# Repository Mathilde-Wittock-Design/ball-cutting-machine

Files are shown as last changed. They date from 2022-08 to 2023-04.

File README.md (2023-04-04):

# Ball Cutting Machine
This project is part of the [Soundbounce Design Project](<https://graduateshowcase.arts.ac.uk/projects/247648/cover>).  
Soundbounce is a product made from reclaimed tennis balls.



## Objectives
The machine should be an assembly of standard tools and accessible to Opendesk manufacturers.  
Opendesk manufacturers are mainly located in North America and Western Europe.  
The machine should be assembled from a downloadable file/template.  

Main objectives:
- [ ] Reduce cutting time.
- [ ] Require minimum effort.
- [ ] Be affordable and accessible.
- [ ] Be safe.

## Propositions
At the moment, the machine can be an adapter that can be attached to a drill press.  
In the future, this machine could probably become an adapter that can be attached to a CNC machine.  
The drill press for cutting tennis balls seems to need an adapter to hold the appropriate cutting tool and a tray to hold the tennis balls in place during cutting.

### Constraints? Guidelines?
Since this is to be shared and intended for makers, it is important to base our choices on repeatability and accessibility.  
Therefore, we need to take into account:  
- Quality brands that are likely to already be in the range of professional makers, such as Fein, Bosch, Makita, and Ryobi.
- Open-source software and easy-to-access documentation that is not paid.
- 3D printing FDM, PLA filament, PETG, and nothing too specific.

### Conceptual Sketches
#### - The Sawing Stand:
sketch1

#### - The Clamping Base for 3 Balls:
sketch2

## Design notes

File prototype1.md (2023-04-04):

# Prototype No. 1

The first version of the "clamping base" is designed to hold a tennis ball while undergoing a vertical cut with a vibrating saw mounted on a drilling stand. The constraints were as follows:  
1. Keeping the ball properly secured despite its loss of volume and density as successive cuts were made.
2. Properly securing the ball against pressure and vibration.
3. Making a straight cut up to the middle of the ball.

Following the guidelines, our solutions to these different problems were as follows:
1. We opted to hold the ball with a spring-loaded clamp that adapts to the different sizes and density changes of the ball during the operation.
2. We added heavy-duty grip tape to the inside of the clamps, as well as screws whose tips come out inside the clamp, in order to create even more resistance to vibration.
3. We made a right-angle table to install the clamps vertically so that we can cut up to half the ball with no obstruction from the clamp. We added tabs to locate every clamp and ease the alignment with the blade.

genPictV1

## Lists of Components
#### Stand

We opted for this sturdy, rigid, and adjustable drill stand, which allows us to adjust the cutting height and the exact positioning of the vibrating saw. And we chose this model of Bosch multitool for its rigid "starlock" clamping ring that allowed us to hold on to it. The use in a fixed station did not require the cordless version, which offers the advantage of being less expensive.



- ["Drilling milling stand BF1240"](<https://www.wabeco-remscheid.de/catalog/category/view/s/bf1240/id/352/>)
- Multi-cutter "Bosch professional GOP 30-28"
- Saw blade "E-Cut SLP Standard HCS 50x65"

#### Clamping base
- Spring clamp "FZ 60 - wolfcraft 3631000"
- Toggle Clamps "GH-201-B"
- Wood Multiplex 18mm
- 3D model to 3D print in [/Files/clamp](https://github.com/Mathilde-Wittock-Design/ball-cutting-machine/tree/main/Files)



#### Tool clamp
- 3D model to 3D print in [/Files/holder](https://github.com/Mathilde-Wittock-Design/ball-cutting-machine/tree/main/Files)



## Assembly

1. Attach the drilling stand to the workbench using at least two bolts.
2. Attach the adapter to the end of the horizontal hexagonal rod so that it is flush with the edge of the rod.
3. Position the vibrating saw in the adapter, tighten the clamping screw slightly, and insert the blade.
4. Bolt the fixed part of the board to the stand without tightening.
5. Place the movable part of the board against the fixed part in the first notch, place a ball in the first clamp, and adjust the fixed part of the board so that the center of the ball is aligned with the center of the blade.
6. Tighten the fixed part of the board.
7. Close the toggle clamps to lock the position of the movable part, then check the alignment of the blade with the board using a square.
8. Lock the square with a clamp and then firmly screw the saw's clamping screw onto the adapter.
9. Adjust the cutting height (Z-axis) and depth (Y-axis) manually (refer to the drilling stand manual).

## Tablet construction

sketch2

- Cut the three parts of the tablet to the dimensions indicated on the diagram.
- The two parts of the flat, horizontal face are cut at a 45° angle like a "French cleat" so that the mobile part slides under the fixed part.
- The third part is fixed at a right angle to the second, composing the mobile part of the tablet.
- In the fixed part, drill two holes so that it can be bolted to the base, then fix it.
- Trace the center of the blade on the fixed part, then make a "dovetail" notch centered on the blade.
- Cut out the negative of this notch and stick it inside to obtain a notch.

dimensions de la tablette

- Cut out a notch in the mobile part of the tablet corresponding to this notch, for each clamp you wish to put on this tablet, the recommended space between these notches is 12/16 cm to provide space for the clamps but also to place the hand outside the cut.
- Determine the location of the clamps centered opposite the notches of the mobile part, on the vertical part, by already positioning a ball in each, in order to center the ball and not the clamp.
Ensure that the ball protrudes sufficiently in height to pass over the horizontal tablet.
- Mark the location of the clamp and outline the spring housing.
- Remove the clamp and hollow out the spring housing location with a wood chisel in the tablet so that it can fit completely and no longer interfere with the stability of the clamp.
- Place the clamp again and fix it by drilling one of the two handles in three points, in order to keep its ability to open and close while fixing it securely.

alignement tablette

---

### Remarques et problèmes rencontrés. 
- le grip des balles
- la flexibilité de la lame
- la mise à l'équerre de la scie // à la tablette

### Recherche du rendement. 
- la pièce de callage de balle, pour faciliter l'alignement des balles. 
- production de plusieurs tablettes
- travail d'équipe
- confort, sécurité et endurance 

### upgrade futur et piste de développement
"Ultrasonic cutter" utilisé dans l'industrie alimentaire.

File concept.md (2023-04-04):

**This machine is designed to be replicated or improved to enable upcycling of tennis balls in a distributed manner. The plans will be published on GitHub under a free license, with attribution (CC BY 4.0).**

## Concept
_"This machine is designed to be reproduced or improved,"_  
meaning it is designed to be manufactured in other fablabs or makerspaces, or improved and adapted as needed.
The design must therefore exclude the use of non-standard components, or provide information on how to make them.
For example, the vibrating saw is not a Bosch but a Fein or a Makita, and the tool holding clamp does not match and must be adapted to the new shape. The editable 3D model is provided to make the update.  
We select tools like Bosch because the brand is reputable, professional, and readily available.

_"and enable upcycling of tennis balls in a distributed way."_  
Upcycling, as opposed to recycling, means transforming or reusing the ball for a new function than what it was originally intended for. Here, the ball is cut in half and finds a new life and function as sound absorption.


source: https://himalayan-made.fr/2020/01/07/upcycler-et-recycler-quelle-est-la-di%EF%AC%80erence/

_"Distributed production:"_  
This is the main proposal of Opendesk. Instead of having a centralized factory, they have a network of workshops for distributed production. This way, the production process is decentralized and potentially associated with local networks for decentralized pickup of the products.


source: https://blogs.aalto.fi/makerculture/2017/10/19/localizing-and-distributing-production/

## License
_"The plans will be published on GitHub under an open license with attribution (CC BY 4.0)."_  
As a consequence of these goals, the plans must be shared openly so that anyone who wants to participate in the ball cutting can do so.

We propose publishing the plans on GitHub, which is a platform that allows for protection, distribution, and collaboration on software, hardware, and other projects.

The suggested license is CC BY 4.0, which is the creative commons version 4.0 with attribution.  
https://creativecommons.org/2013/11/25/ccs-next-generation-licenses-welcome-version-4-0/  

which mean that 
### you are free to:
**Share** — copy and redistribute the material in any medium or format  
**Adapt** — remix, transform, and build upon the material for any purpose, even commercially.  
### Under the following terms:
**Attribution** — You must give appropriate credit, provide a link to the license, and indicate if changes were made. You may do so in any reasonable manner, but not in any way that suggests the licensor endorses you or your use.  
**ShareAlike** — If you remix, transform, or build upon the material, you must distribute your contributions under the same license as the original.

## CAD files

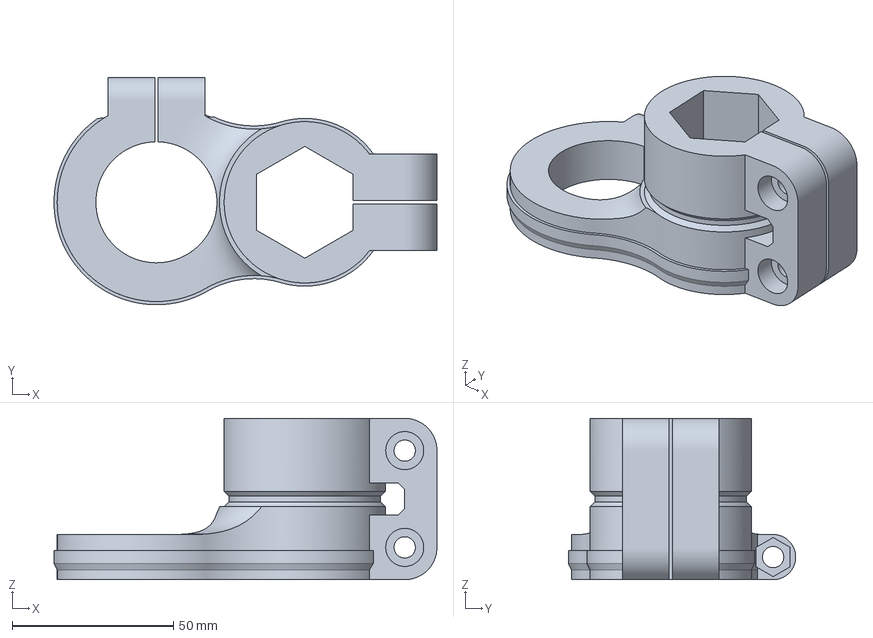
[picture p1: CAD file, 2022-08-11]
Files/SB_Clamp.3mf
118.7 x 70.5 x 50.0 mm

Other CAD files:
Files/SB_Clamp.f3d
Files/SB_Holder.f3d

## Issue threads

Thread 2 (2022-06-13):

rédaction du concept

nicolasdb, 2022-06-13:
**Cette machine est conçue pour être reproduite ou améliorée et permettre le surcyclage (up- cycling) des balles de tennis de manière distribuée. Les plans seront publiés sur github sous licence libre, avec attribution (CC BY 4.0).**

voici la phrase décortiquée. J'imagine que tu connais déjà certains principes, mais ceci pourra aussi servir pour la publication.
Je suis convaincu qu'un brevet fermé , comme son nom l'indique, ferme la porte à toutes ces externalités positives. Et à l'inverse, une licence libre ouvre le champ des possibilités.

Cette machine est conçue pour être reproduite ou améliorée
c'est à dire conçue pour répondre à l'objectif d'être fabriquée dans d'autres fablabs, makerspaces ou améliorée, adaptée selon les besoins.
Le design doit donc exclure l'usage de composant non standard ou, à défaut, fournir les informations pour le fabriquer.
Par exemple, la scie vibrante n'est pas une Bosch mais une Fein ou une Makita, la pince de maintien de l'outil ne correspond pas, et doit être adaptée à la nouvelle forme. Le modèle 3D éditable est fourni pour réaliser la mise à jour.
Et nous sélectionnons les outils comme Bosch parce que la marque est réputée, professionnelle et est disponible facilement.

et permettre le surcyclage (up- cycling) des balles de tennis de manière distribuée.
upcycling vs recycling: recycler les balles, c'est les broyer et réutiliser la matière première. upcycling, c'est transformer ou réutiliser la balle pour une nouvelle fonction que ce qu'elle avait à l'origine. Ici, elle est coupée en 2 et elle trouve une nouvelle vie et une autre fonction: l'absorption acoustique.

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
source: https://himalayan-made.fr/2020/01/07/upcycler-et-recycler-quelle-est-la-di%EF%AC%80erence/

production distribuée:
C'est la proposition d'opendesk.
Pas d'usine centralisée, mais un réseau d'atelier pour une production distribuée, potentiellement associée à son réseau local pour une collecte de balles décentralisée

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
source: https://blogs.aalto.fi/makerculture/2017/10/19/localizing-and-distributing-production/

Les plans seront publiés sur github sous licence libre avec attribution (CC BY 4.0).
En conséquence de ces objectifs, les plans doivent être partagés et ouverts afin que chaque lieu voulant participer d'une manière ou d'une autre à la découpe de balle, puisse être autorisé à le faire.
Nous proposons le mode de publication le plus courant et adapté pour la publication de ces plans. C'est via github, une plateforme qui permet la protection, la diffusion et la collaboration sur des projets software, hardware et bien d'autres.
voici un exemple probalement familier https://github.com/opendesk/smartdesk

Github en 3min:
https://youtu.be/w3jLJU7DT5E

La licence libre proposée est CC BY 4.0, c'est la creative commons version 4.0 avec attribution.
https://creativecommons.org/2013/11/25/ccs-next-generation-licenses-welcome-version-4-0/
CC BY 4.0 se résume à ceci:
You are free to:
Share — copy and redistribute the material in any medium or format
Adapt — remix, transform, and build upon the material for any purpose, even commercially.
Et correspond légalement à celà https://github.com/idleberg/Creative-Commons-Markdown/blob/master/4.0/by.markdown

nicolasdb, 2022-06-13:
**This machine is designed to be replicated or improved to allow up-cycling of tennis balls in a distributed manner. The plans will be published on github under a free license, with attribution (CC BY 4.0).**

_"This machine is designed to be reproduced or improved"_
that is to say, designed to meet the objective of being manufactured in other fablabs, makerspaces or improved, adapted as needed.
The design must therefore exclude the use of non-standard components or, failing that, provide the information to make them.
For example, the vibrating saw is not a Bosch but a Fein or a Makita, the tool holding clamp does not match, and must be adapted to the new shape. The editable 3D model is provided to make the update.
And we select tools like Bosch because the brand is reputable, professional and readily available.

_"and allow up-cycling of tennis balls in a distributed way."_
upcycling vs. recycling: recycling balls means crushing them and reusing the raw material. upcycling means transforming or reusing the ball for a new function than what it was originally. Here, it is cut in 2 and it finds a new life and another function: sound absorption.

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
source: https://himalayan-made.fr/2020/01/07/upcycler-et-recycler-quelle-est-la-di%EF%AC%80erence/

_"distributed production:"_
This is the main proposal of Opendesk.
No centralized factory, but a network of workshops for a distributed production, potentially associated with its local network for a decentralized pick-up of balls

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
source: https://blogs.aalto.fi/makerculture/2017/10/19/localizing-and-distributing-production/

Closed 2022-06-13.

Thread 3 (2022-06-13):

photos développement prototype

Mathieu1060, 2022-06-13:
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
Support de fixation des pinces pour le maintient des balles de tennis.

Mathieu1060, 2022-06-13:
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

nicolasdb, 2022-06-13:
Attention à l'encombrement de la machine.
Mais avantage de celle ci est qu'elle possède une bague de fixation en métal.
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

Mathieu1060, 2022-06-13:
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

nicolasdb, 2022-06-21:
**mkhdsqsqdlkqlk** _italic_

Mathieu1060, 2022-06-28:
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

Mathieu1060, 2022-08-10:
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

nicolasdb, 2022-08-10:
# Description de l'assemblage
## croquis
concept et description de la proposition.

## liste des composants et matériels. Références
- socle
- bosch
- pinces
- tablette
- adaptateur

- [ ] kuhfdkhfdsk

### assemblage
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

## Remarques et problèmes rencontrés.
- le grip des balles
- la flexibilité de la lame
- la mise à l'équerre de la scie // à la tablette

## Recherche du rendement.
- la pièce de callage de balle, pour faciliter l'alignement des balles.
- production de plusieurs tablettes
- travail d'équipe
- confort, sécurité et endurance

## upgrade futur et piste de développement
"Ultrasonic cutter" utilisé dans l'industrie alimentaire.

nicolasdb, 2022-08-10:
## liste des composants et matériels. Références

- socle : Drilling milling stand BF1240

Nous avons opté pour ce socle de perçage robuste et aux options multiples, permètant de regler la hauteur de coupe et le positionnement exacte de la scie vibrante.

- bosch

Nous avons choisis une scie vibrante bosh standart pour sa forme et son utilisation simple, mai égallement car ont peut ce la procurer facillement, nous avons privilegié une machine filaire:
    -Pas de batteries à recharger
    -Meilleurs performances
    -Prix plus bas
    -Pas besoin de bouger

- adaptateur

L'adaptateur à été réaliser en 3D sur Fusion 360, puis imprimé en 3D sur une Prusa mini en PLA.
Cet adaptateur à pour fonction de fixer la scie vibrante bosh au socle de perçage.
Nous avons également rajouté un serre joint plus haut permetant l'ajustement de l'équerrage entre la lame et la tablette avant de serrer fermement l'adaptateur à la scie.

- tablette

La première version de la tablette avait pour but de maintenir une balle de tennis pendant qu’elle subissait une coupe droite verticale avec une scie vibrante montée sur un support colonne.
Les problématiques était les suivantes:
    1-Continuer à maintenir suffisamment la balle malgré sa perte de volume et de densité au fur et mesure des coupes successive.
    2-Maintenir suffisamment la balle face à la pression et les vibrations.
    3-Effectuer une coupe droite jusqu’à la moitié de la balle.

    Suite à ce bilan nos réponses à ces différentes problématique ont été les suivantes:
        1-Nous avons choisi de maintenir la balle à l’aide d’une pince à ressort s’ adaptant aux différentes tailles et aux changements de densités de la balle durant l’opération.
        2-Pour ce faire nous avons ajouter de l’ antidérapant à l’intérieur des pinces, ainsi que des vis, dont les pointes ressortent vers l’intérieur de la pince, afin d’ obtenir une mâchoire.
        3- Nous avons conçu une tablette en angle droit, afin de positionner les pinces à la verticale, dans le but de pouvoir effectuer une coupe jusqu’à la moitié de la balle sans que la pince ne gène.

La deuxième version de cette tablettes reprend donc toutes les spécificités de la première, mais elle est cette fois adapté pour 3 balles:
    Une partie de cette tablette est donc mobile, glisse le long de la partie fixe couper de part et d’autre à 45°. Des encoches en face de chaque balles et une queue d’aronde sur la partie fixe permettent un calage rapide et régulier. Des pinces sauterelles permettent de maintenir la partie mobile pendant la coupe.

Cette version démontre la possibilité de travailler à la chaîne en multipliant les tablettes mobiles et/ou les postes de découpes afin de répartir les rôles: 1 (ou plusieurs) à la coupe / 1 (ou plusieurs) au placement des balles pour la prochaine coupe.

- pinces

Mathieu1060, 2022-08-11:
[dimensions de la tablette](https://github.com/Mathilde-Wittock-Design/ball-cutting-machine/files/9307215/cotes.de.la.plaque.pdf)

nicolasdb, 2022-08-11:
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

Mathieu1060, 2022-08-11:
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

Mathieu1060, 2022-08-11:
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

nicolasdb, 2022-08-11:
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

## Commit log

2022-06-20 add 3D files
    [Soundbounce clamp.3mf, Soundbounce clamp.f3d]
2022-08-10 add 3Dmodel
    [SupportTennisBall v5.f3d]
2022-08-11 ajout proto et add 3D files
    [SB_Clamp.3mf, SB_Clamp.f3d, SB_Holder.3mf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]
